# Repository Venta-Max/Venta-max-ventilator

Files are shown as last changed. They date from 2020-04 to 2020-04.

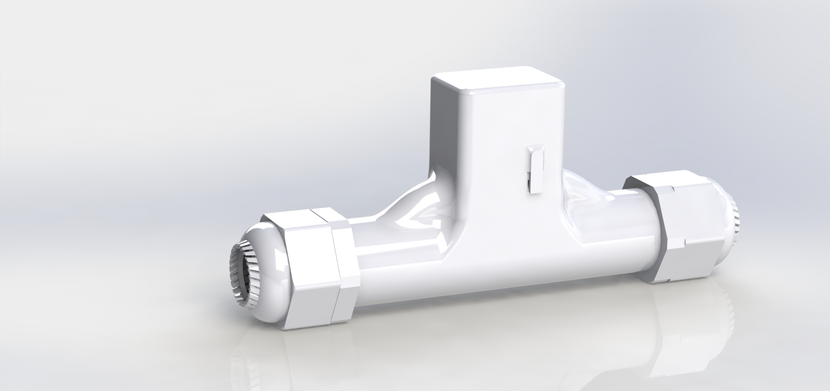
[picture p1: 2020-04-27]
CAD Design/V1.1/Renders/Flow3.JPG

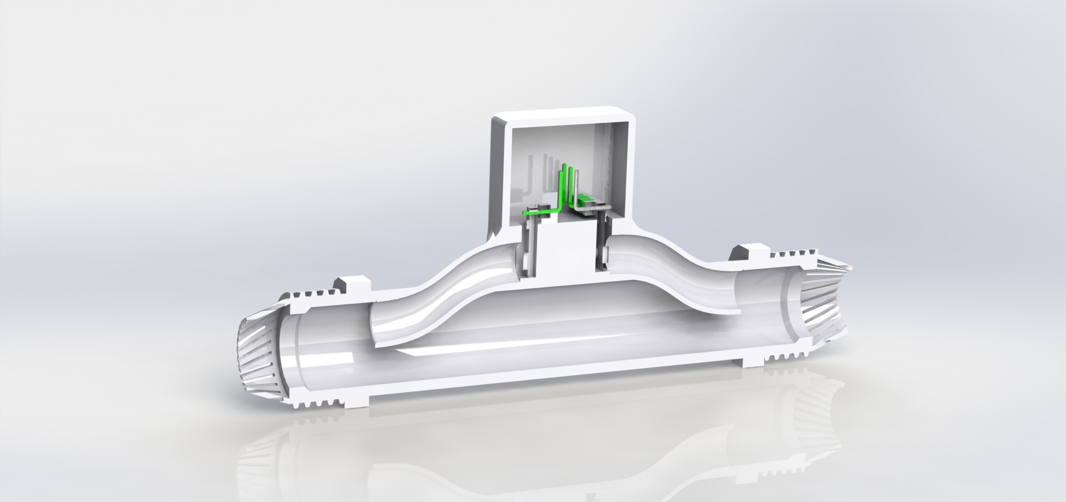
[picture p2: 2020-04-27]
CAD Design/V1.1/Renders/Flow1.JPG

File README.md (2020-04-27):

# Venta-max-mechanical-ventilator
Our ventilator can assure safe and stable breathing in acute pneumonia patients and can directly help in keeping severe COVID-19 patients breathing when their lungs aren’t capable anymore of delivering a sufficient amount of oxygen by itself. Mainly by controlling the pressure of air inside the lungs in both inhaling and exhaling, respiratory rate and the concentration of oxygen delivered. The ventilator is modular, easy to maintain and clean, and made of widely available materials and sensors with HEPA filtered inlet and outlet. Furthermore, it can be built locally using simple tools and rapid prototyping with simple 3D printed connections. The device can operate using both 110V and 220V with the ability to use internal batteries for more than 180 minutes when not connected to a building AC circuit.  A simple, interactive, user-friendly app allows the user/ doctor to control the mechanical and electrical systems using a touch screen to govern the pressure of the air required as well as the exhalation to inhalation ratio. The doctor can control the inspiratory pressure up to 40cmH2O and the expiratory pressure up to 25cm H2O. He can also control the respiratory rate from 5 to 40 breaths per minute and change oxygen concentration according to the patient’s condition. This ventilator is smart and its behavior is easily monitored as the feedback mechanism implemented, along with the sensors used, make sure the pressure and oxygen delivered just before the lungs match those required and alarms the doctor otherwise.

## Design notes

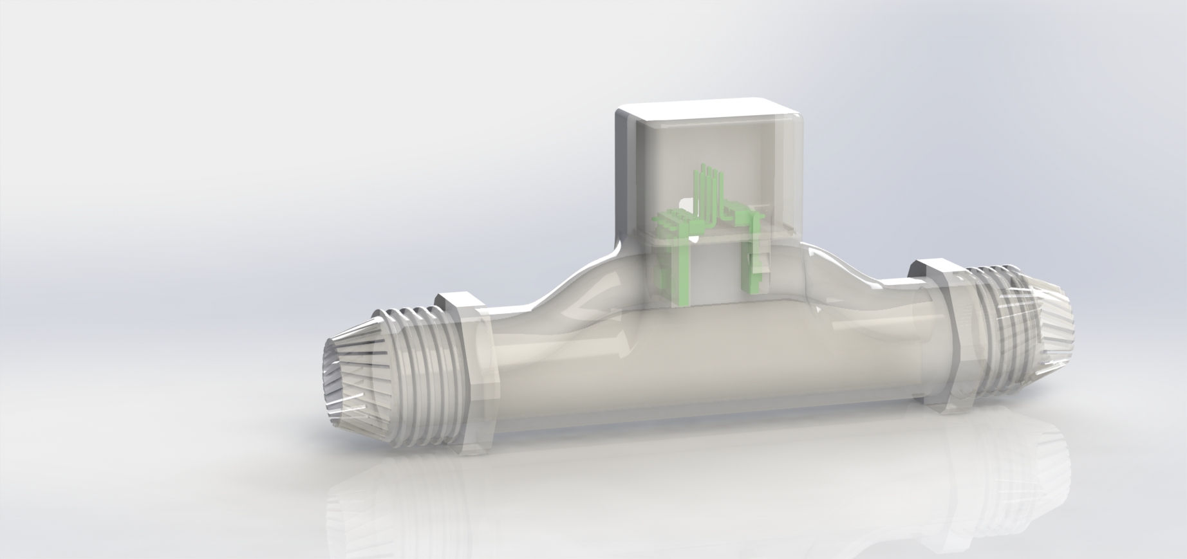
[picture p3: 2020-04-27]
CAD Design/V1.1/Renders/Flow2.JPG

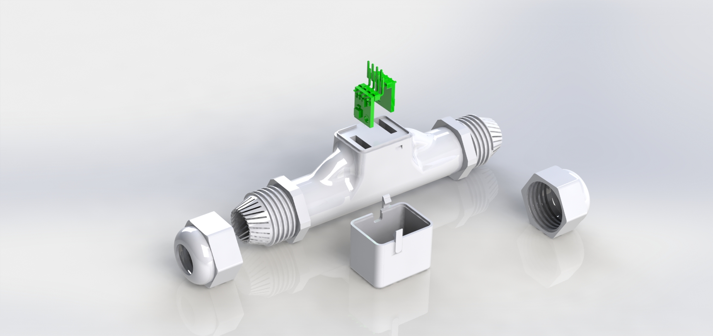
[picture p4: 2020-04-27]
CAD Design/V1.1/Renders/Flow4.JPG

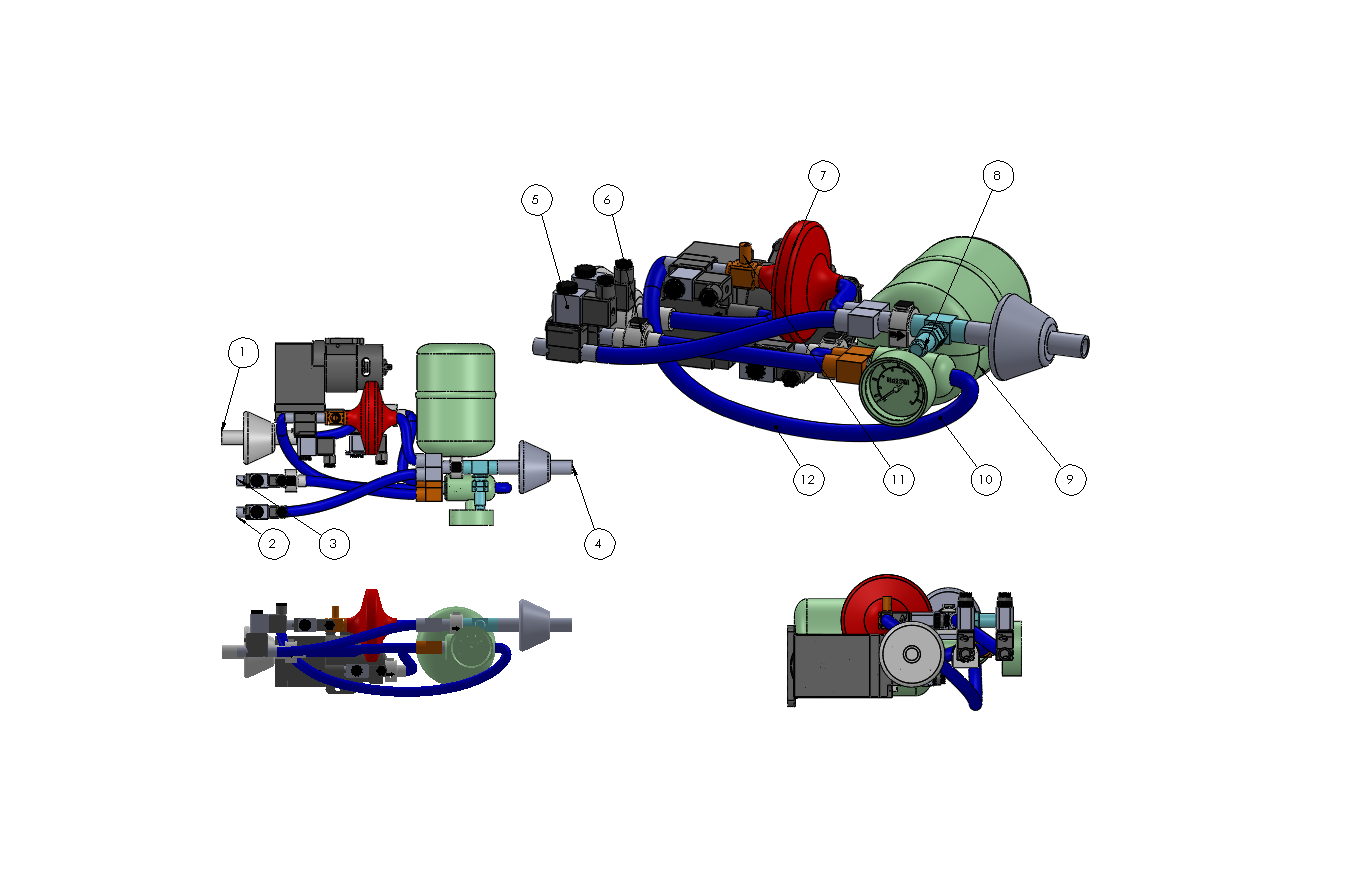
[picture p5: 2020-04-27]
CAD Design/V1.1/Ventilator2.PNG

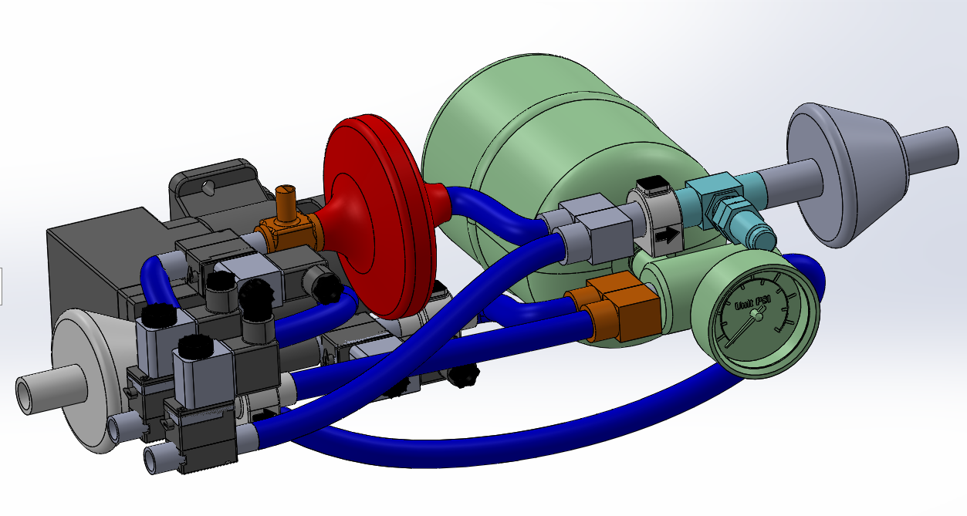
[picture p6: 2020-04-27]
CAD Design/V1.1/Capture.PNG

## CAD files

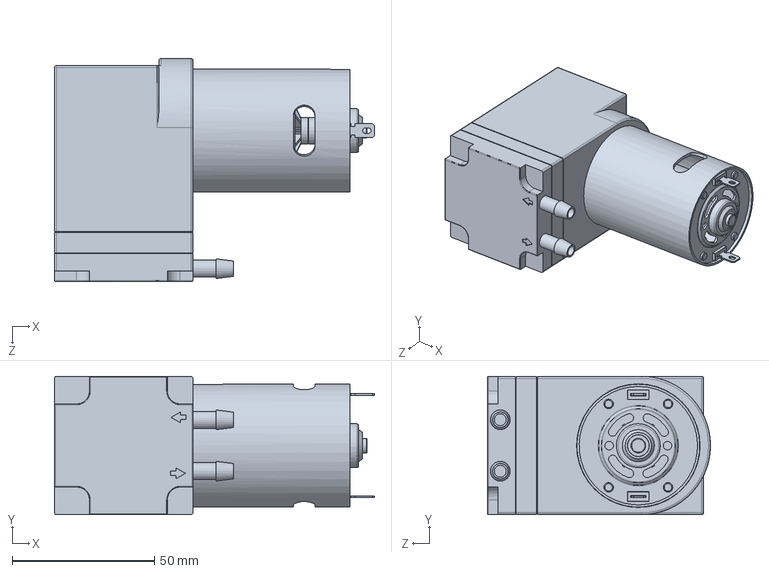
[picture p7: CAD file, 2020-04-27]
CAD Design/V1.1/Air Pump.SLDPRT
112.5 x 48.7 x 78.4 mm

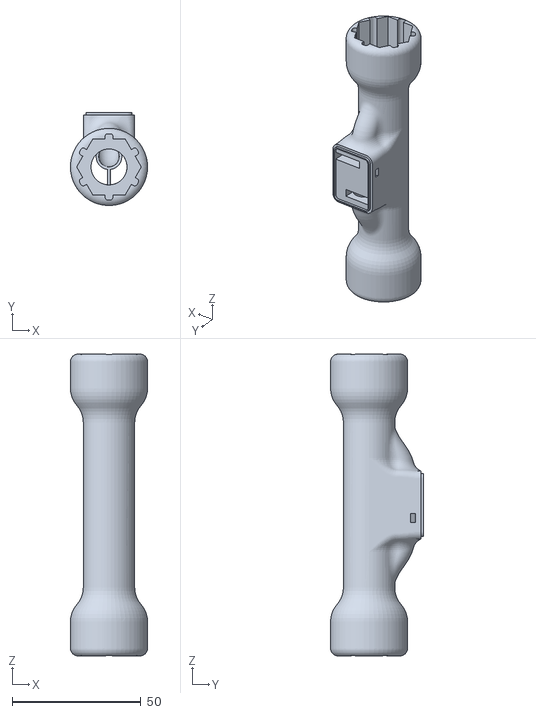
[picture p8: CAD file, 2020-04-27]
CAD Design/V1.1/CAM/Sensor Body_2 X 1.STL
30.0 x 36.1 x 117.5

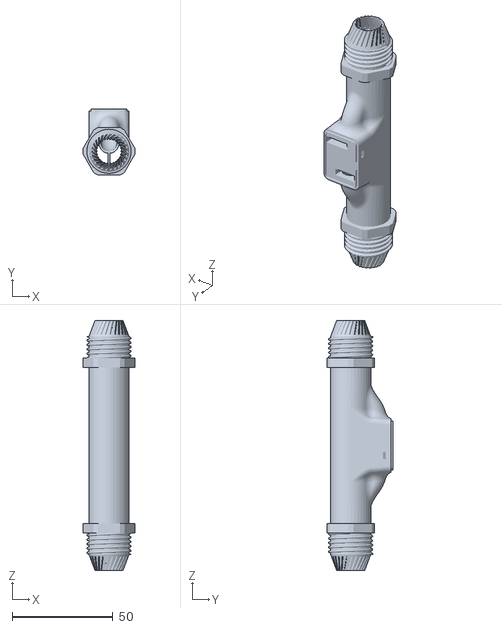
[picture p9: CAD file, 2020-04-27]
CAD Design/V1.1/CAM/Sensor Body X 1.STL
26.0 x 33.1 x 124.4

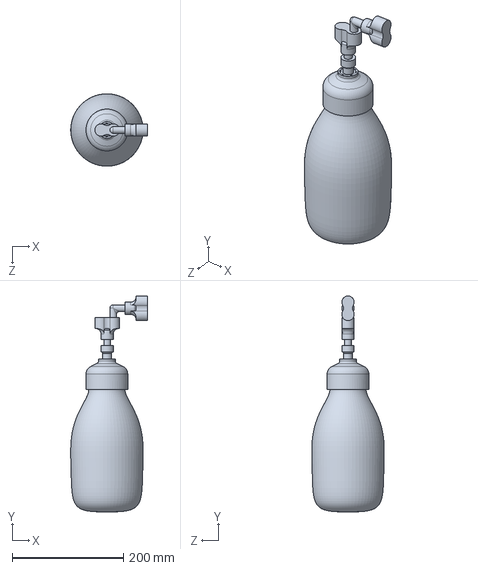
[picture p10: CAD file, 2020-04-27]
CAD Design/V1.1/Tank.SLDPRT
137.6 x 387.6 x 130.0 mm

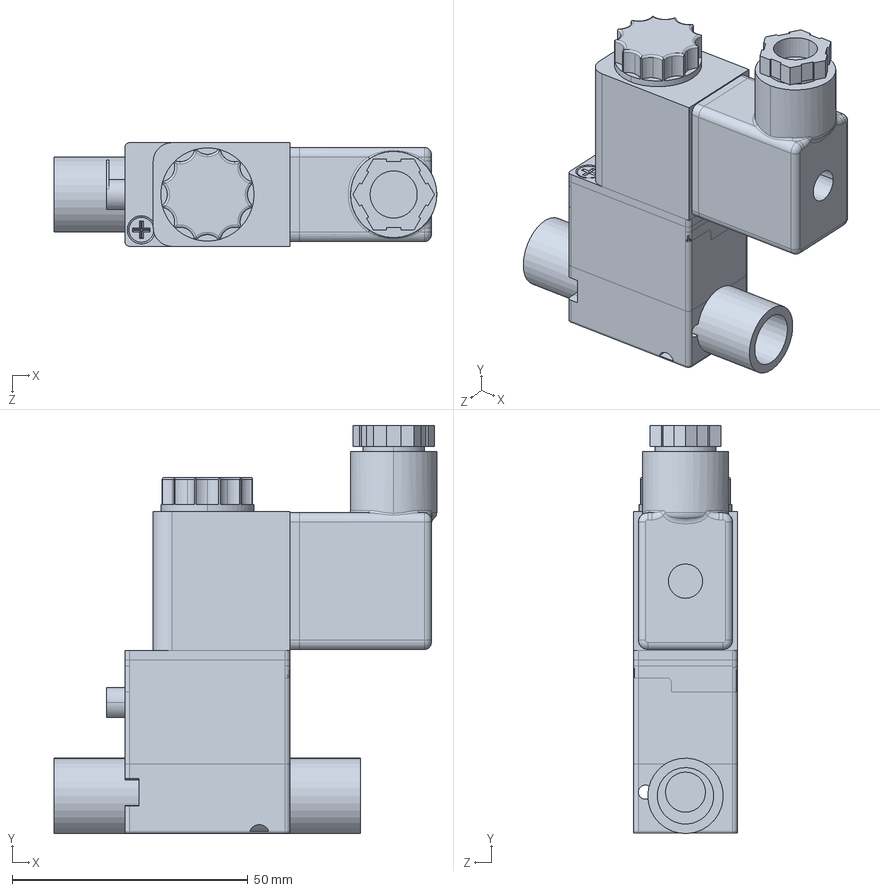
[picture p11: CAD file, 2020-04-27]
CAD Design/V1.1/Pnomatic Solenoid 1 to 1.SLDPRT
81.2 x 86.5 x 22.0 mm

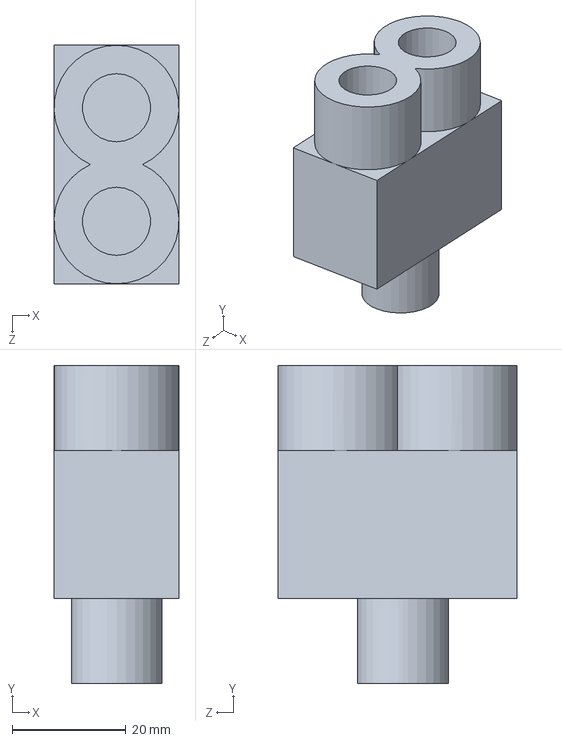
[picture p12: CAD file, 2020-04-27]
CAD Design/V1.1/Pneumatic T Oneway Valves.SLDPRT
22.0 x 56.0 x 42.0 mm

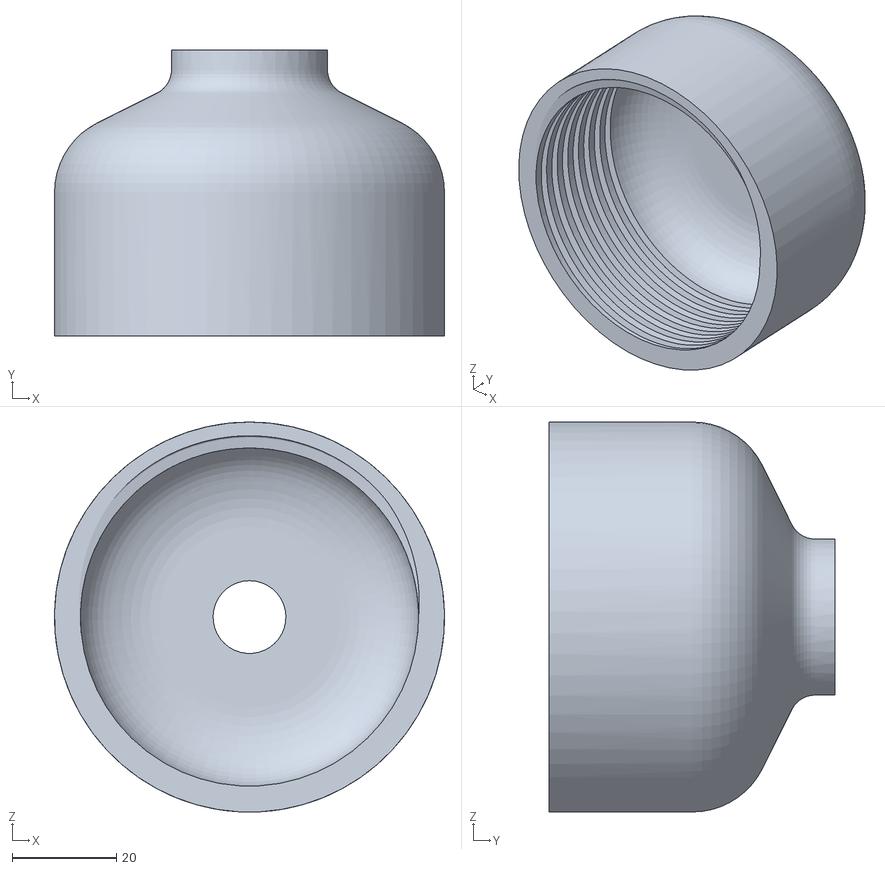
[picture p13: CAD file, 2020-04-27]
CAD Design/V1.1/CAM/Tank Fitting X 1.STL
75.0 x 55.0 x 75.0

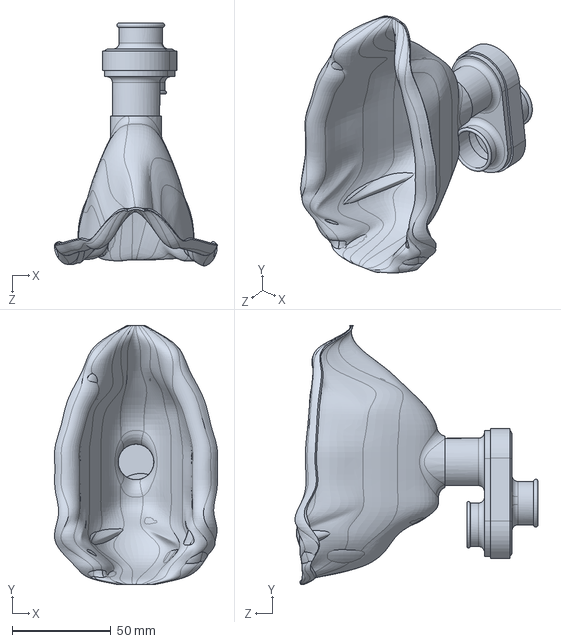
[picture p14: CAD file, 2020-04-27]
CAD Design/V1.1/medical mask1.SLDPRT
82.5 x 131.0 x 122.9 mm

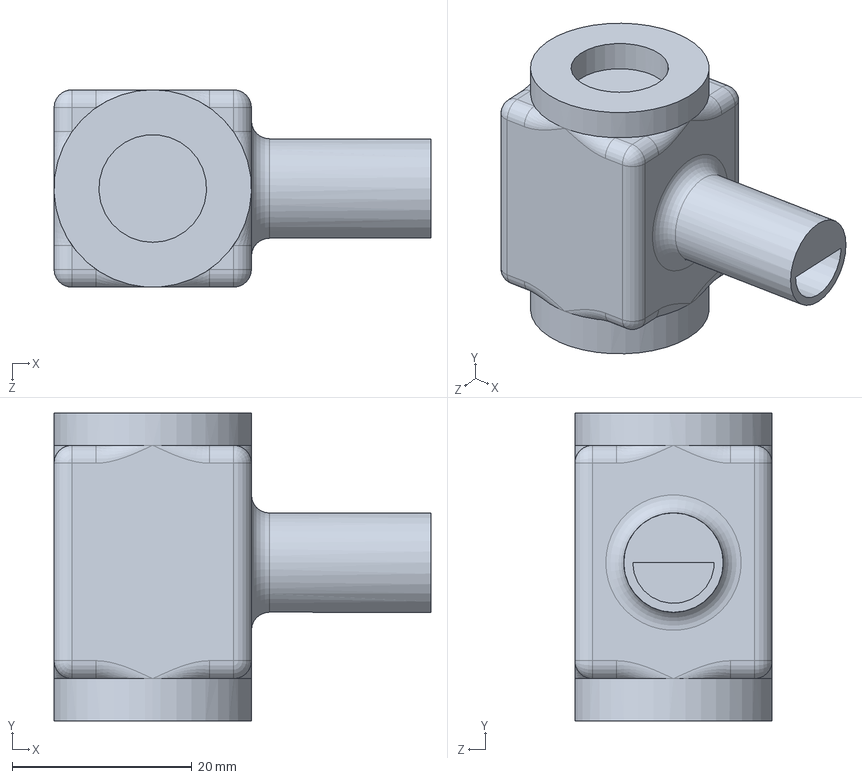
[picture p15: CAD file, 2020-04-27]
CAD Design/V1.1/Safety Relief Valve.SLDPRT
42.0 x 34.3 x 22.0 mm

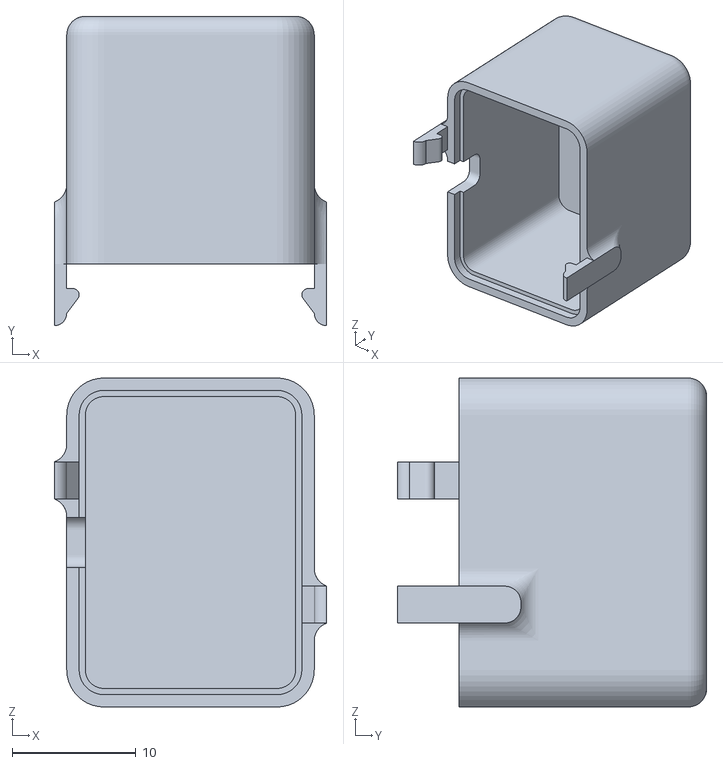
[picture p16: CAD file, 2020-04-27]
CAD Design/V1.1/CAM/Cover X 2.STL
22.0 x 25.0 x 26.6

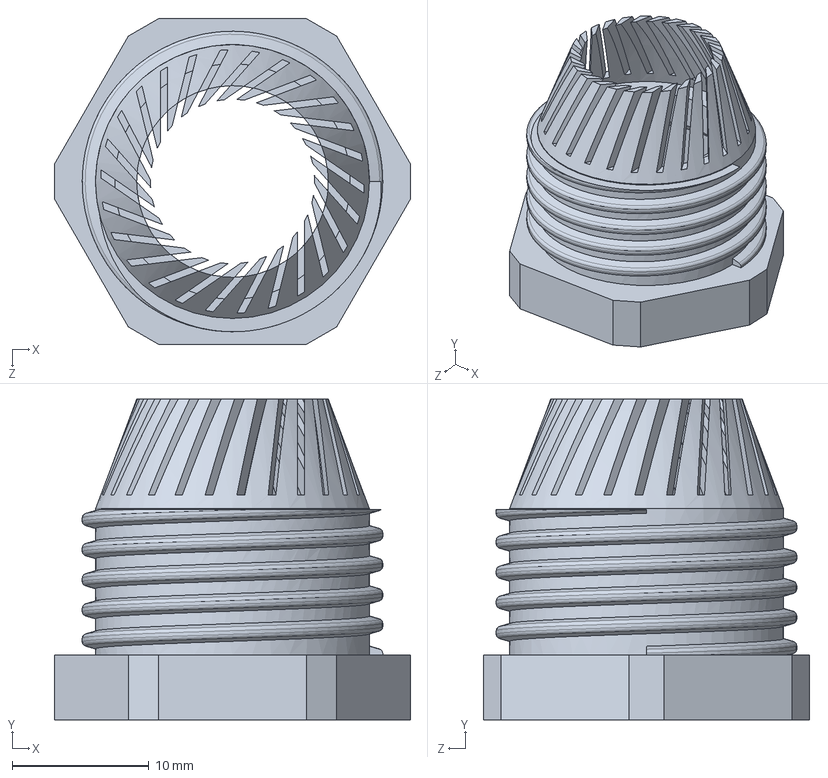
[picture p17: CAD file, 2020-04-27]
CAD Design/V1.1/Gland 12mm.SLDPRT
26.0 x 23.4 x 23.8 mm

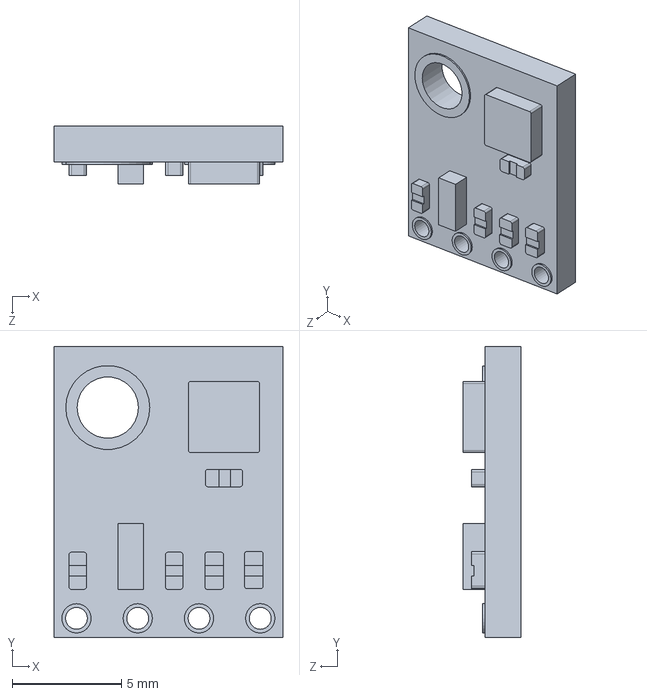
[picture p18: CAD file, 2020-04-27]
CAD Design/V1.1/bmp180.SLDPRT
10.4 x 13.3 x 2.66 mm

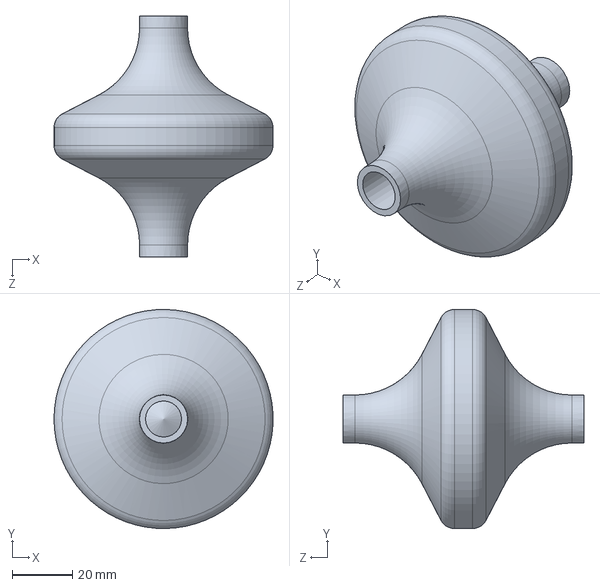
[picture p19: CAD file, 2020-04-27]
CAD Design/V1.1/Heating Element.SLDPRT
72.8 x 72.9 x 80.0 mm

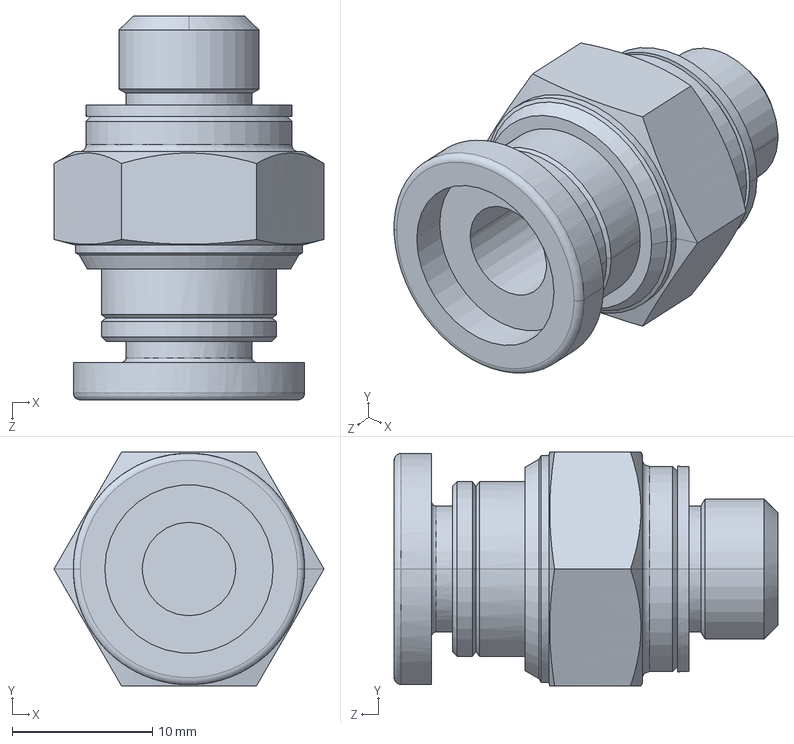
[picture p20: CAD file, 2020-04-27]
CAD Design/V1.1/Coupler.SLDPRT
19.2 x 16.7 x 27.4 mm

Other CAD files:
CAD Design/V1.1/CAM/Cover.sldprt
CAD Design/V1.1/CAM/Sensor Body.sldprt
CAD Design/V1.1/Selonoid.SLDPRT
CAD Design/V1.1/Filter.SLDPRT
CAD Design/V1.0/Air Pump.SLDPRT
CAD Design/V1.0/Assembly/Body1.sldprt
CAD Design/V1.0/Assembly/Body11.sldprt
CAD Design/V1.0/Assembly/Body12.sldprt
CAD Design/V1.0/Assembly/Body13.sldprt
CAD Design/V1.0/Assembly/Body14.sldprt
CAD Design/V1.0/Assembly/Body15.sldprt
CAD Design/V1.0/Assembly/Body16.sldprt
CAD Design/V1.0/Assembly/Body17.sldprt
CAD Design/V1.0/Assembly/Body18.sldprt
CAD Design/V1.0/Assembly/Body19.sldprt
CAD Design/V1.0/Assembly/Body20.sldprt
CAD Design/V1.0/Assembly/Body22.sldprt
CAD Design/V1.0/Assembly/Body23.sldprt
CAD Design/V1.0/Assembly/Body24.sldprt
CAD Design/V1.0/Assembly/Body25.sldprt
CAD Design/V1.0/Assembly/Body26.sldprt
CAD Design/V1.0/Assembly/Body27.sldprt
CAD Design/V1.0/Assembly/Body3.sldprt
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

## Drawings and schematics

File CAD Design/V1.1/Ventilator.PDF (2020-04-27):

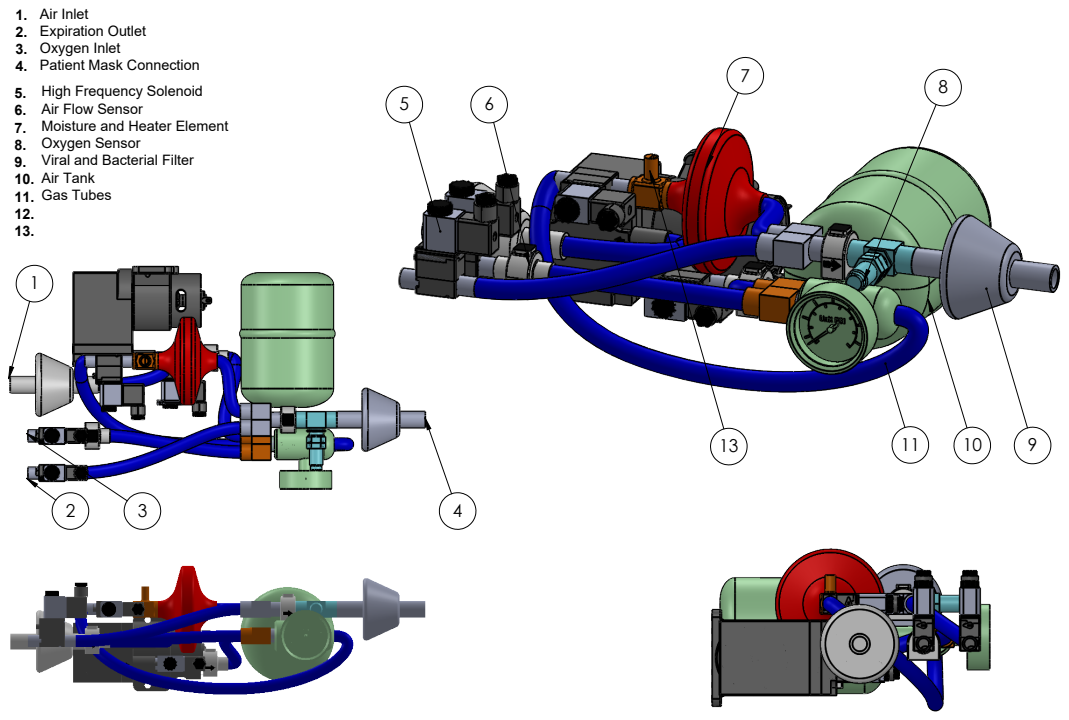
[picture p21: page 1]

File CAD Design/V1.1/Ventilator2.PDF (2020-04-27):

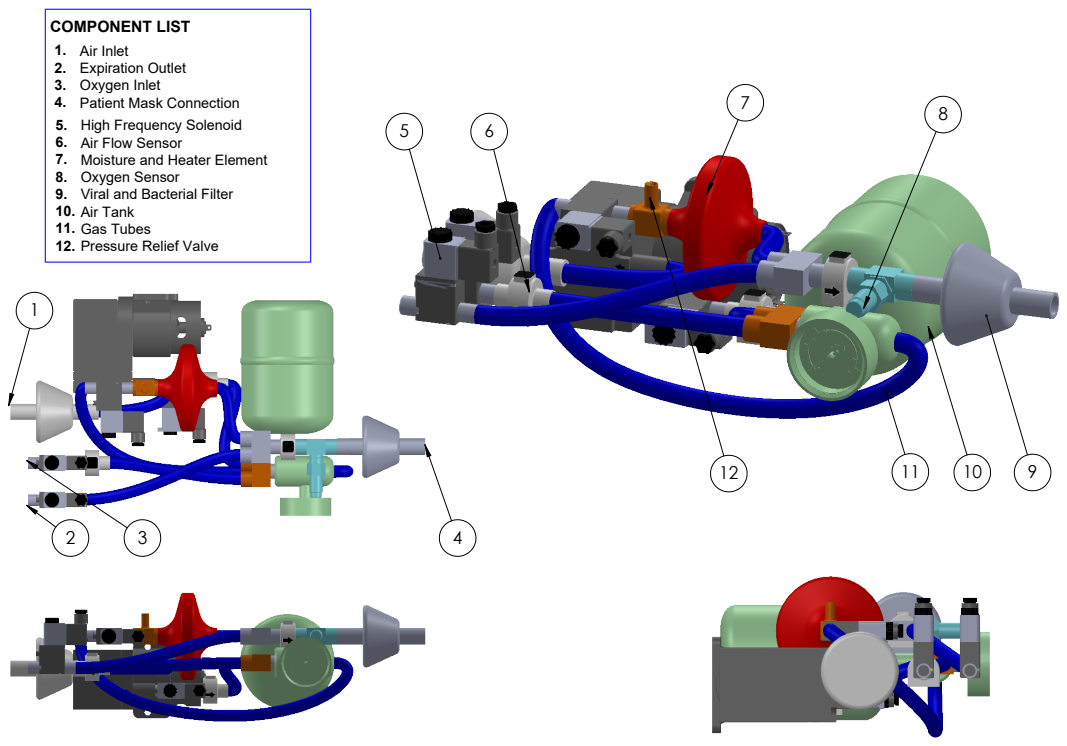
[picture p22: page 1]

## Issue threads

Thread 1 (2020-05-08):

how to integrate this sensor?

noorkhokhar99, 2020-05-08:
how to integrate oxygen sensor for 100%

AhmedARadwan, 2020-05-17:
We are assuming a linear output so in the code we are calibrating at standard condition which is around 20.9% oxygen in air and we have another point which is zero oxygen zero voltage output. So we get the slope between the two points.

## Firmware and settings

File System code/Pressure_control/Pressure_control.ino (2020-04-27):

//#include "Oxygen_sensor.h"
//#include "Pressure_sensor.h"
//#include "Actuators.h"
//#include <PID_v1.h>
//
//float oxygen_offset_ = 0;
//float pressure_offset_ = 0;
//
//
//double Setpoint, Input, Output;
//double Kp=2, Ki=5, Kd=1;
//PID deltaP_control(&Input, &Output, &Setpoint, Kp, Ki, Kd, DIRECT);
//float p_H2o = 0;
//
//
//void setup() {
//  Serial.begin(9600);
//  init_actuators();
//  turn_on_air_valve(0);
//  turn_on_oxygen_valve(0);
//  turn_on_inhale_valve(0);
//  turn_on_exhale_valve(100);
//  delay(5000);
//  oxygen_offset_ = calibrate_sensor();
//  pressure_offset_ = pressure_calibration();
////  while(1);
//  
//  
//}
//
//void loop() {
//  p_H2o = get_pressureh2o(pressure_offset_);
//  turn_on_air_valve(100);
//  turn_on_oxygen_valve(100);
//  
//  if (p_H2o >= 60){
//    turn_on_inhale_valve(0);
//    turn_on_exhale_valve(70);
//  }
//  if (p_H2o < 20){
//    turn_on_inhale_valve(70);
//    turn_on_exhale_valve(0);
//  }
//  
////  float oxygen = get_oxygen_percentage(oxygen_offset_);
//  Serial.println(p_H2o);
//  
////  delay(1);        // delay in between reads for stability
//}


#include "Actuators.h"
#include "MedianFilterLib.h"
#include <Wire.h> //Including wire library

MedianFilter<float> medianFilter(20);
//float timeMean = 0;
float oxygen_ampient = 0;
float voltage_output = 0;
float oxygen_concentration = 0;

//
int Time = 0;
double I_Time, E_Time;
int OxygenPercentage;
float In_line[6];
double P1 = 0, P2 = 0, D_P = 0;
int flag = 0;
int32_t frequency = 80; //frequency (in Hz)
//


//
int valve_Air = 9;
int valve_Oxygen = 10;
int valve_In = 11;
int valve_Ex = 12;
//

void setup()
{
  Serial.begin(9600);
  pinMode(9, OUTPUT); pinMode(10, OUTPUT);
  pinMode(11, OUTPUT); pinMode(12, OUTPUT);
  init_actuators();
  oxygen_ampient = calibrate_sensor();

  digitalWrite(12,0);
  digitalWrite(11,1);
  Serial.begin(9600);
  int x = 0;
  Serial.println("IN_Pressure, EX_Pressure, I2E, Re_Rate, Oxygen, Type_Patient");
  while (x < 6)
  { int flag = 0;
    while (Serial.available())
    {
      In_line[x] = (float)Serial.parseFloat();
      Serial.println(In_line[x]);
      if (flag == 0)
      {
        x++;
        flag = 1;
      }
    }
  }
  Serial.println("End Of Readings");
  for (int i = 0; i < 6; i++)
  { Serial.print(In_line[i]);
    Serial.print(",");
  }
  Serial.println();
  I_Time = (In_line[3] / (60 * (pow(In_line[2], -1) + 1)));
  E_Time = I_Time * pow(In_line[2], -1);
  Serial.println(I_Time);
  Serial.println(E_Time);
}

////index of date
//IN_Pressure --> 0
//EX_Pressure --> 1
//I2E --> 2
//Re_Rate --> 3
//Oxygen --> 4
//Type_Patient -->5 (1 for male , 2 for femail , 3 for child).

void loop()
{
  Mixer_VC(In_line[4]);
  Oxygen_Sensor();
}


void Mixer_VC(float Oxygen_conc)
{
  int PWM;
  if (Oxygen_conc == 20)
  {
    turn_on_air_valve(100);
    turn_on_oxygen_valve(0);
  }
  else if (Oxygen_conc <= 60 && Oxygen_conc > 20)
  {
    PWM =  ((Oxygen_conc - 20) * 100 / (100 - Oxygen_conc));
    turn_on_air_valve(0);
    turn_on_oxygen_valve(PWM);
  }
  else if (Oxygen_conc <= 100 && Oxygen_conc > 60)
  {
    PWM = ((100 - Oxygen_conc) * 100 / (Oxygen_conc - 20));
    turn_on_air_valve(PWM);
    turn_on_oxygen_valve(0);
  }
}

void Oxygen_Sensor()
{
  voltage_output = medianFilter.AddValue(analogRead(A0) * (5.0 / 1024.0));
  oxygen_concentration = (voltage_output / oxygen_ampient) * 20.9;
  Serial.println(oxygen_concentration);
}

float calibrate_sensor()
{
  float median = 0;
  for (int i = 0 ; i < 20 ; i++) {
    median = medianFilter.AddValue(analogRead(A7) * (5.0 / 1024.0));
    delay(100);
  }
  return median;
}

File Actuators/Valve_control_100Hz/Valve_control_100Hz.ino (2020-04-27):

#include <TimerOne.h>

#define air_valve 9
#define oxygen_valve 10
#define inhale_valve 11
#define exhale_valve 12

bool toggle_air_valve = false;
bool toggle_oxygen_valve = false;
bool toggle_inhale_valve = false;
bool toggle_exhale_valve = false;

bool state_air_valve = false;
bool state_oxygen_valve = false;
bool state_inhale_valve = false;
bool state_exhale_valve = false;

int counter_air = 0;
int counter_oxygen = 0;
int counter_inhale = 0;
int counter_exhale = 0;

int duty_air = 0;
int duty_oxygen = 0;
int duty_inhale = 0;
int duty_exhale = 0;

void Toggle(void)
{
  // air valve
  if (toggle_air_valve){
    
    if (counter_air <= duty_air && counter_air >= 0) {
      state_air_valve = true;
    } 
    if (counter_air > duty_air){
      state_air_valve = false;
    }
    digitalWrite(air_valve, state_air_valve);
  }
  counter_air++;
  if (counter_air >= 100){
    counter_air = 0;
   }
  if (!toggle_air_valve) digitalWrite(air_valve, toggle_air_valve);


  // oxygen valve
  if (toggle_oxygen_valve){
    
    if (counter_oxygen <= duty_oxygen && counter_oxygen >= 0) {
      state_oxygen_valve = true;
    } 
    if (counter_oxygen > duty_oxygen){
      state_oxygen_valve = false;
    }
    digitalWrite(oxygen_valve, state_oxygen_valve);
  }
  counter_oxygen++;
  if (counter_oxygen >= 100){
    counter_oxygen = 0;
   }
  if (!toggle_oxygen_valve) digitalWrite(oxygen_valve, toggle_oxygen_valve);


  // inhale valve
  if (toggle_inhale_valve){
    
    if (counter_inhale <= duty_inhale && counter_inhale >= 0) {
      state_inhale_valve = true;
    } 
    if (counter_inhale > duty_inhale){
      state_inhale_valve = false;
    }
    digitalWrite(inhale_valve, state_inhale_valve);
  }
  counter_inhale++;
  if (counter_inhale >= 100){
    counter_inhale = 0;
   }
  if (!toggle_inhale_valve) digitalWrite(inhale_valve, toggle_inhale_valve);


  // exhale valve
  if (toggle_exhale_valve){
    
    if (counter_exhale <= duty_exhale && counter_exhale >= 0) {
      state_exhale_valve = true;
    } 
    if (counter_exhale > duty_exhale){
      state_exhale_valve = false;
    }
    digitalWrite(exhale_valve, state_exhale_valve);
  }
  counter_exhale++;
  if (counter_exhale >= 100){
    counter_exhale = 0;
   }
  if (!toggle_exhale_valve) digitalWrite(exhale_valve, toggle_exhale_valve);



  
  
}


void setup() {
  Timer1.initialize(100);
  Timer1.attachInterrupt(Toggle);
  Serial.begin(9600);

}

void loop() {
  for (int i = 0; i<100; i++){
    toggle_air_valve = true;
    toggle_oxygen_valve = true;
    duty_air = i;
    duty_oxygen = i;
    interrupts();
    delay(20);
  }

}
